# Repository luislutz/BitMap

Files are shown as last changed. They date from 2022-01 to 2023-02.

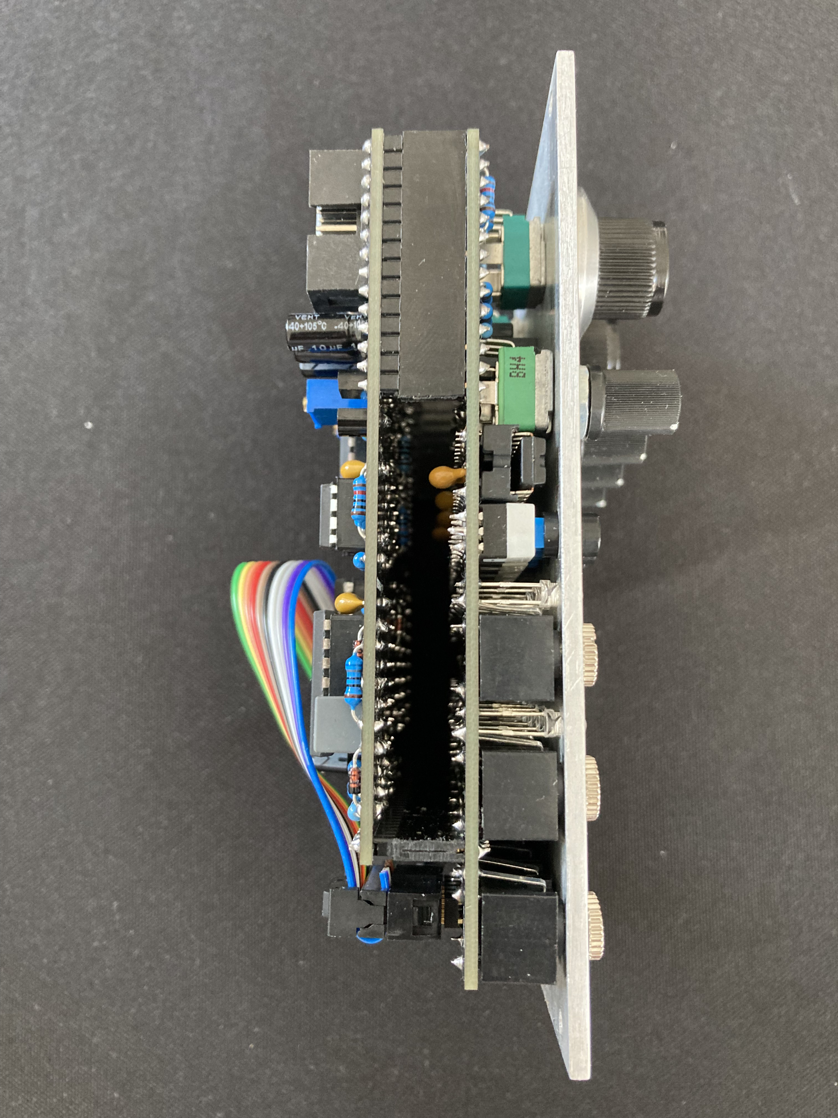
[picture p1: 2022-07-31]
Pictures/Side View.jpeg

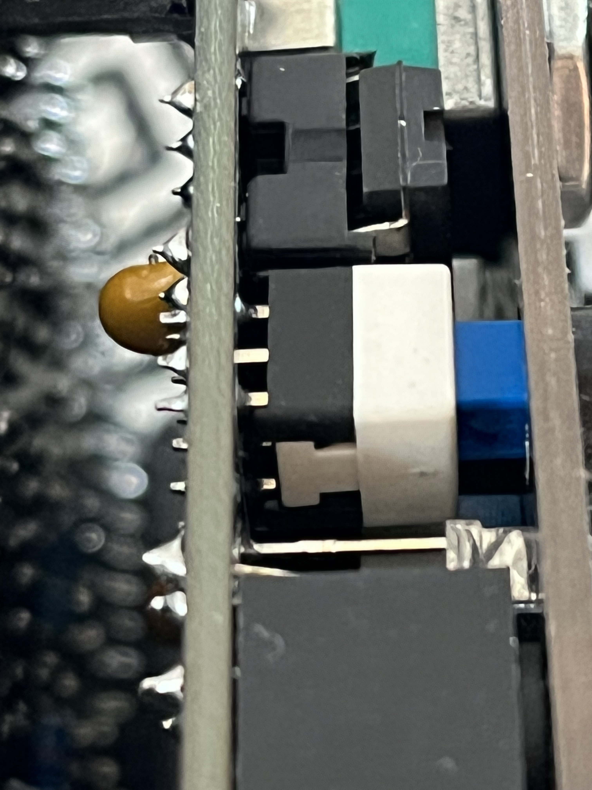
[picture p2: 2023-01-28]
Pictures/963E008B-FA3E-4BF9-BDF7-06B0E4106F40.jpeg

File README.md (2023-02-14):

# BitMap
Multifunction Eurorack Module with 8 Bit parallel ADC and DAC in the Heart. Main selling points:
- most versatile Bitcrusher in Eurorack with passive LPF
- infinite Sample and Hold with slew, works with 1v/oct pitch CV!
- Halftone Chromatic, Chromatic and weird scales Quantizer (every 2nd, 4th, 8th, 16th)
- inspiring Drum/Gate Sequencer with 8 Channels
- VCA and Ringmodulator
- White Noise, 8 types of digital noise and processed White Noise (Bitcrushed, Sample Rate reduced and Filtered to your taste)

## Features and Functions:

Conversion of analog voltage in 8 Bit digital value
Possibility of swapping individual bits and switching them off manually, 
aswell as removing the bits in order via the voltage controlled Bitcrush-Knob
Reconversion of digital 8 Bit value in analog voltage

ADC and DAC can be used as seperate units with the same clock (onboard pulsegenerator or external trigger/gates):

ADC: 1 analog input, 8 digital bit outputs derived from the input voltage (Gates), additional Clip output wich goes high when the input voltage is bigger than the ADC range, this produces hard clipping

DAC: 8 digital inputs (Gates), 1 analog output derived from the digital input values. Possibitlity to set the refence voltage of the DAC externally via an analog gain input, works as a VCA with unipolar Voltage or Ringmodulator with bipolar Voltage

Normalled white noise to the analog input of the ADC aswell as a seperate unprocessed noise output. This gives direct access to 9 flavours of Digital Noise at the ADC Bit outputs and Clip output and a processed white noise at the analog output of the DAC without having to add some other modules or cables. The processed white noise can of course be bitcrushed and samplerate reduced as you wish aswell. Random Voltages in S and Hold style are achievable too with really slow clock rate. With the passive Slew limiter (LPF) at the output the noise can be filtered too and it is possible to slew the Sample and Hold Voltages.

Because the value of the incoming analog voltage is stored in Digital realm. The module does act as a Sample and Hold circuit with infinite holding time and zero voltage drop. Using this module to sample and hold pitch CV is no problem.

The coolest feature by far is the precise mapping of the 256 steps in 8 Bit to the V/Oct scale at the analog input and output. To set the module up for quantizing Pitch CV, just turn the input and output level knobs all the way up. Now a Voltage of 0 (C3) at the input equals a digital word of 10000000, C#3 would be 10000010, D3 = 10000100, D#3 = 10000110 and so on. one Sem,itone equals two steps in the Digital realm. So the minimum voltage value will be -5.33V (00000000, G#-3) and the maximum voltage is 5.25 (11111110, D#8). The Quantizing range is therefor over 10 Octaves of Notes. There are many possibilities for quantizing pitch cv. For Chromatic quantizing, disable the lowest value bit. if you want everey 2nd, 4th, 8th semitone and so on,disable more bits or make any weird combination of bits to make weird scales that are impossible using a normal quantizer. Normal scales like Major Minor or Phrigyian are not so easy to replicate with this module.

## Different Use Cases:

- Voltage controlled Bitreducing of CV and Audio signals
- Voltage controlled Reducing of Sample Rate for CV and Audio Signals (S&H)
- Random Voltage and Gate Source
- Sequencing Drums with mutes (up to 9 channels)
- Quantizing of pitch CV (Chromatic and unusal scales)
- VCA and Ringmodulator (after AD->DA Conversion on the Output)
- Sequencer for pitch CV
- infinite Sample and Hold with external trigger
- Pitch Sequence Transformation to related, but different Sequences
- Slew and Low pass filtering of output with switchable range (passive)
- Strange Wavefolder (swapping or switching individula bits of Audio)
- Distortion (hardclipping at 10vpp)
- Noise source (1 unprocessed Noise white noise outoput, 9 times digital noise with different flavours, and one 8 bit white noise processable with Bitmap as you wish) 
- Compatible with Leibniz system from Xaoc via Leibniz headers on the back of the module!

## Building Instructions:

This is no easy build! Althought it is mostly throughhole, the Module is really packed with Components and ICs.
The hardest part is to solder the 0603 SMD Resistors and keep them unharmed during the rest of the soldering

Start with the 0603 SMD resistors on the backside of the front PCB!

Using Leibniz Subsystem:
There are 9 Jumpers on the front PCB. if you solder these jumpers, the optional connectors for the Leibniz subsystem are bridged and wont be needed anymore. If you want to use the Leibniz subsystem now or in the Future, please make sure you dont solder the jumpers and solder the connectors for the Leibniz subsystem.
Before soldering the Thonkiconn Jacks (3.5mm mono jacks) make sure to solder the Leibniz Headers first. Make sure the pins of the Leibniz connector is flush with the Frontside of the PCB, that way they dont interfere with the 3.5mm Mono Jacks on the oter side of the PCB.

After you have made your decision, start putting everything else in by starting with the most slim parts (Resistors, diodes) and end with the Biggest parts (Elko Caps, trimmers, pin headers)
Solder the panel components with the panel already mounted on them to make sure the parts will align with the holes in the PCB Panel

## Calibraton:

Set Up: 
- SampleRate Knob ~70% to the right
- Bitcrush Knob 100% to the left
- Input Level Knob 100% to the left
- CV Scale Knob 100% to the left
- Slew Pot 100% to the left
- Output Pot 100% to the right
- All individual Bit Buttons are not pressed, e.g. Bits are all active!

there are 6 calibrating trimpotentiometers in total to be adjusted:

1. Input Offset trim RV5 10K:
Turn the Input Level Knob on the Panel completely to the left first. Listen to the Noise Output Jack. Turn the Noise Trim Potentiometer completely down, so that there is absolutely no Nosie left at the Noise Output Jack. This should result in less flickering of the Bit LEDS on the Panel (This is really important). Now youre set for precise calibration. Adjust the Input Offset Trim Potentiometer so that the LEDs light up with this pattern from left to right without flickering: 00000001 (EG Only BIT8 is set active)

2. Input Scale trim RV4 10K:
Take a constant voltage source with exactly 5V (coming from a sequencer or similar) and plug it in the analog voltage input. Turn the Input Level Knob on the Frontpanel completely up (100% to the right). Adjust the Input Scale Trim Potentiometer so that LEDs light up with this pattern from left to right: 00011111    ---> repeat Step 1. and Step 2. until it stays at the correct LED-Pattern with the corresponding input voltage and no jitter.

3. Output Offset trim RV6 2K:
Keep the precise 5V source plugged in. Turn the Input Level Knob on the panel to zero again. Connect the output to a Voltage Meter or to the V/Oct input of an Oscillator that is already well calibrated to 1V/Oct. Make sure you see the Pattern 00000001 on the LEDs. Adjust the Output Offset Trim until the Output Voltage equals excactly 0V or your oscillator doesnt change pitch when unpluuging the cable from the V/Oct input (should be the case for a good calibrated VCO with 0V at the cable)

4. Output Scale trim RV9 2K:
Keep the precise 5V source plugged in. Turn the Input Voltage Knob on the Panel to max (100% to the right). Now the LED-Pattern should be (00011111) again. Leave the Analog Voltage Output connected to the oscillator or the Voltage Meter. Adjust the Output Scale Trim until the output matcehs excactly 5 volts or the Oscillator is playing 5 Octaves above when compared to Step 3.
--> your Input and Output Scales and Offsets are now set correctly to 1V/Oct

5. Max Sample Rate trim RV12 2K:
Feed a Sinewave into the analog input Jack. Listen to the output of the Module. Turn the Sample Rate Knob on the panel to max value (100% to the right). Adjust the Sample Rate Trim to minimal noise on the output (Hint: if the sample rate just exceeds audible range its perfect there). if the Sample Rate trim is set to high. The ADC stalls when turning the SR pot all the way to the Right, you can unstall the ADC by turning it quite down, but its better to set that trimmer in a way that the ADC doest lock at all when the Sample Rate Pot is at its max Setting (100% to the right)

6. Noise Level trim RV3 100K: 
Turn the Input Level Knob again completely to the left. Now turn the Noise trimpot up until there is a slight flickering at the LEDs on the Panel (because the dac is very quickly switching States because of increased signal noise at the input). Turn it slightly back so that the flickering stops. Noise level is now set to Max Level without interference to the input Voltage. Any higher and the Readings of Voltages to the Analog Voltage input get inprecise and noisy. For max precision on Pitch CV you can even turn the noise trim completely down :) if your more after noisy behaviour it doesnt matter that much and you can turn up the noise quite abit :D

if you have any questions regarding the building or calibration Process you can write me an email to luis.lutz95@gmail.com 

Thanks for thaking the challenge to build one of these!!!

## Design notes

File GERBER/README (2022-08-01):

Gerber files for Production of PCB. Noncommercial use only. If your interested in selling these PCBs please contact me beforehand. If you want to build this for yourself, go ahead and have fun!

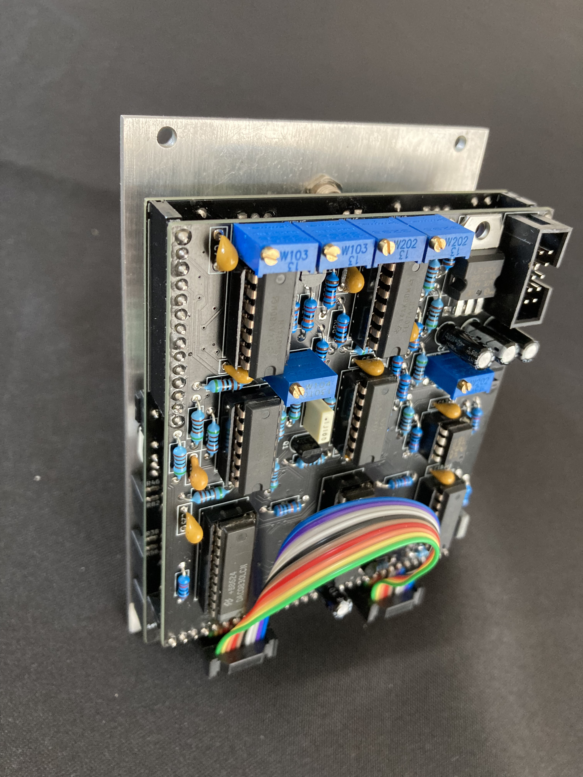
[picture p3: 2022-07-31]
Pictures/Diagonal View.jpeg

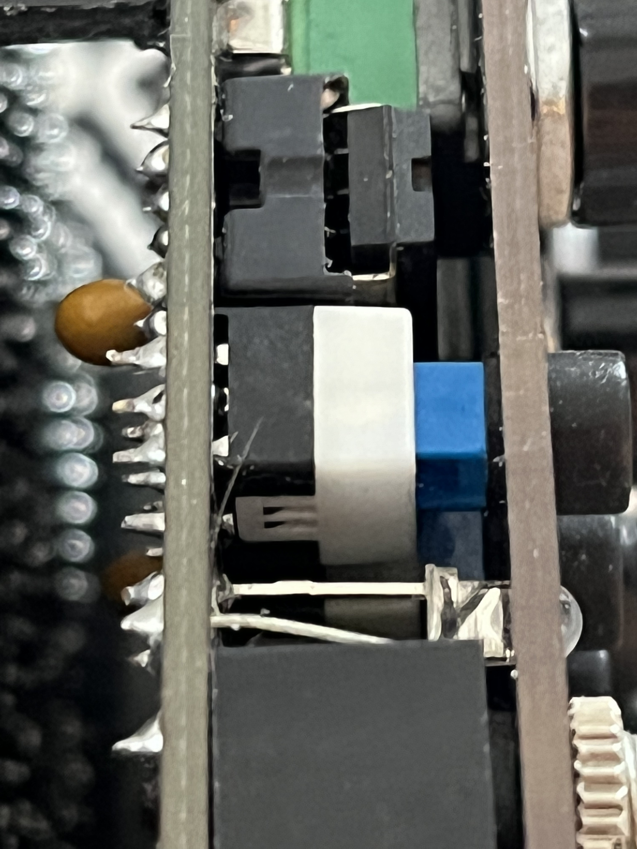
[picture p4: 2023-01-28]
Pictures/B39D2387-7268-4ADA-9052-7F4AAE6AAACA.jpeg

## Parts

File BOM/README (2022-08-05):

This is the Bill of Materials to order every component you need to successfully build a BitMap model after you got you PCBs and Panel ready :)

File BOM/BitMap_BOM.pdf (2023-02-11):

Part number on Schematic | Value | Amount | Package | Link for ordering | Comment
Resistors SMD
R31, R32, R33, R34, R35, R36, R37, R38,
R83, R83, R85, R86, R87, R88, R89, R90
1K | 16 0603 SMD | 1K Ohm 1/10W 1% 0603 SMD Chip Resistors (taydaelectronics.com)
R72, R76, R77, R78, R79, R80, R81, R82 | 10K | 8 0603 SMD | 10K Ohm 1/10W 1% 0603 SMD Chip Resistors (taydaelectronics.com)
R39, R40, R41, R42, R43, R44, R45, R46 | LED resistors ADC ~3.3K | | 8 0603 SMD | 4.7K Ohm 1/10W 1% 0603 SMD Chip Resistors (taydaelectronics.com) | Resitor for setting the brightness on the ADC LEDs Running on 5V. Recommended value for clear yellow LEDs is 3.3K. Best is to test with the LEDs you want to use and test for brightness with some resistor values with 5V before ordering the SMD resistors
R49, R50, R51. R52, R53, R54, R55, R56 | LED resistors DAC ~75K | | 8 0603 SMD | 100K Ohm 1/10W 1% 0603 SMD Chip Resistors (taydaelectronics.com) | Resitor for setting the brightness on the DAC LEDs. Running on 12V. Recommended value for clear green LEDs is 75K. Best is to test with the LEDs you want to use and test for brightness with some different resistor values with 12V before ordering th SMD resistors Resistors THT
R74 | 470R | 1 THT 1/4W | Save time Easy Ordering Page for 1/4W 1% Resistors (taydaelectronics.com)
R68 | 680R | 1 THT 1/4W | Save time Easy Ordering Page for 1/4W 1% Resistors (taydaelectronics.com)
R70, R15, R23, R29, R30, R69, R92, R94 | 1K | 9 THT 1/4W | Save time Easy Ordering Page for 1/4W 1% Resistors (taydaelectronics.com) | R29 is the Resistor which sets the brightness of the Clip LED running on 5V. Recommended value for clear red LED is 1K. Best is to test with the LEDs you want to use and test for brightness with some resistor values with the right supplyvoltage before ordering th SMD resistors
R63 | 1.8K | 1 THT 1/4W | Save time Easy Ordering Page for 1/4W 1% Resistors (taydaelectronics.com)
R5, R6, R7, R8, R9, R10, R11, R12, R16, R17,
R18, R19, R20, R21, R22
5.1K | 15 THT 1/4W | Save time Easy Ordering Page for 1/4W 1% Resistors (taydaelectronics.com)

R24, R26, R25, R27, R28, R47, R48, R57,
R58, R65, R66, R67, R71, R75, R91, R93
10K | 16 THT 1/4W | Save time Easy Ordering Page for 1/4W 1% Resistors (taydaelectronics.com)
R59, R62 | 20K | 2 THT 1/4W | Save time Easy Ordering Page for 1/4W 1% Resistors (taydaelectronics.com)
R73 | 22K | 1 THT 1/4W | Save time Easy Ordering Page for 1/4W 1% Resistors (taydaelectronics.com)
R2, R60, R61 | 47K | 3 THT 1/4W | Save time Easy Ordering Page for 1/4W 1% Resistors (taydaelectronics.com)
R15 | 91K | 1 THT 1/4W | Save time Easy Ordering Page for 1/4W 1% Resistors (taydaelectronics.com)
R1, R3, R95, | 100K | 3 THT 1/4W | Save time Easy Ordering Page for 1/4W 1% Resistors (taydaelectronics.com)
R4, | 200k | 1 THT 1/4W | Save time Easy Ordering Page for 1/4W 1% Resistors (taydaelectronics.com)
R14 | 220K | 1 THT 1/4W | Save time Easy Ordering Page for 1/4W 1% Resistors (taydaelectronics.com)
R64 | 1M | 1 THT 1/4W | Save time Easy Ordering Page for 1/4W 1% Resistors (taydaelectronics.com)
Capacitors
C4, C5, C6, C7, C8, C9, C10, C11, C12, C13,
C14, C15, C16, C17, C18, C25
100n | 16 Ceramic | https://www.taydaelectronics.com/100nf-50v-multilayer-monolithic-ceramic-capacitor-2-54mm-vishay.html
C21 | 22n | 1 Film | 22nF 0.022uF 100V 5% Polyester Film Box Type Capacitor (taydaelectronics.com)
C20 | 68n | 1 Film | 68nF 0.068uF 100V 5% Polyester Film Box Type Capacitor (taydaelectronics.com)
C1 | 100n | 1 Film | 100nF 0.1uF 100V 5% Polyester Film Box Type Capacitor (taydaelectronics.com)
C23 | 680n | 1 Film | 680nF 0.68uF 100V 5% Polyester Film Box Type Capacitor (taydaelectronics.com)
C2, C3, C19, C24 | 10u | 4 Elko | 10uF 50V 105C Radial Electrolytic Capacitor 5x11mm (taydaelectronics.com)
Diodes
D1 | Clip LED | 1 LED 3mm round LED 3mm Red Water Clear Ultra Bright (taydaelectronics.com)
D2, D3, D4, D5, D6, D7, D8, D9 | LEDs ADC | 8 LED 3mm round LED 3mm Orange Water Clear (taydaelectronics.com) | Tayda has no yellow LEDs at the moment….
D10, D11, D12, D13, D14, D15, D16, D17 | LEDs DAC | 8 LED 3mm round LED 3mm Green Water Clear Super Bright (taydaelectronics.com)
D19 | BAT43 | 1
D18, D20 | 1N4148 | 2 | 1N4148 Switching Signal Diode (taydaelectronics.com)
Variable Resistors
RV3 | 100K | 1 Trim | 100K OHM TRIMMER POTENTIOMETER CERMET 25 TURNS 3296W (taydaelectronics.com)
RV6, RV9, RV12 | 2K | 3 Trim | 2K OHM CERMET TRIMMER POTENTIOMETER 25 TURNS 3296W (taydaelectronics.com)
RV4, RV5, RV14 | 10K | 3 Trim | 10K OHM TRIMMER POTENTIOMETER CERMET 25 TURNS 3296W (taydaelectronics.com)
RV10 | 10K Knurled Shaft | 1 Pot | 10K OHM Linear Taper Potentiometer Spline Shaft PCB Mount 9mm (taydaelectronics.com) | linear Taper
RV2, RV11, RV8 | 100K Knurled Shaft | 3 Pot | 100K OHM Linear Taper Potentiometer Spline Shaft PCB Mount 9mm (taydaelectronics.com) | linear Taper
RV1, RV7 | 100K Round Shaft | 2 Pot | 100K OHM Linear Taper Potentiometer Round Shaft PCB 9mm (taydaelectronics.com) | linear Taper
Transistors
Q1, Q3, Q4 | BC547 | 3 TO-92 | BC547 Transistor NPN 45V 0.1A (taydaelectronics.com)
Q2 | BC557 | 1 TO-92 | BC557 Transistor PNP 45V 0.1A TO-92 BC557B-KEC/P (taydaelectronics.com)
Jacks and Connections
J1, J2, J4, J5, J6, J7, J8, J9, J10, J11, J12, J13, J14, J15, J16, J17, J18, J19, J20, J21, J22, J23, J24, J25 | Thonkiconn type Mono Jack | 24 | | PJ-3001F 3.5mm Mono Phone Jack (taydaelectronics.com)
J3 | Pin Header 2x5 Male Boxed | 1 | 10 Pin Box Header Connector 2.54mm (taydaelectronics.com)
J32, J33 | Pin Header 2x5 Male P2.54 | 2
J27, J30 | Pin Header 1x14 Female | 2 | 40 Pin 2.54 mm Single Row Female Pin Header (taydaelectronics.com) | Cut to lenght!
J26, J31 | Pin Header 1x14 Male | 2 | 40 Pin 2.54 mm Single Row Pin Header Strip (taydaelectronics.com) | Cut to lenght!
J28 | Pin Header 1x31 Female | 1 | 40 Pin 2.54 mm Single Row Female Pin Header (taydaelectronics.com) | Cut to lenght!
J29 | Pin Header 1x31 Male | 1 | 40 Pin 2.54 mm Single Row Pin Header Strip (taydaelectronics.com) | Cut to lenght!
Switches
S1, S2, S3, S4, S5, S6, S7, S8, S9 | DPDT latching switch 7x7mm | 9 | PUSH BUTTON SWITCH DC 30V 0.1A DPDT 7x7mm (taydaelectronics.com)
Integrated Circuits
U1 | MCP6002 | 1 DIP-8
U2, U3, U4, U5 | TL074 | 4 DIP-14 | TL074 Quad Operational Amplifier J-FET PDIP-14 TL074CN (taydaelectronics.com)
U8 | CD4069 | 1 DIP-14 | CD4069UBE CD4069 4069 Hex Inverter IC (taydaelectronics.com)
U6, U7 | LM324 | 2 DIP-14 | LM324N LM324 324 Low Power Quad Op-Amp IC (taydaelectronics.com)
U9, U10 | CD4066 | 2 DIP-14 | CD4066 4066 IC CMOS QUAD BILATERAL SWITCH (taydaelectronics.com)
U11 | L7805 | 1 TO-220-3 | LM7805 L7805 7805 Voltage Regulator IC 5V 1.5A (taydaelectronics.com)
U12 | TL431 | 1 TO-92 | TL431ACL TL431 PRECISION SHUNT REGULATOR (taydaelectronics.com)
IC1 | ADC0820CCN | 1 DIP-20
IC2 | DAC0830LJ | 1 DIP-20
IC - Sockets
E1 | IC Socket | 1 DIP-8 | 8 pin DIP IC Socket Adaptor Solder Type (taydaelectronics.com)
E2, E3, E4, E5, E6, E7, E8, E9, E10 | IC Socket | 9 DIP-14 | 14 pin DIP IC Socket Adaptor Solder Type (taydaelectronics.com)
EC1, EC2 | IC Socket | 2 DIP-20 | 20 pin DIP IC Socket Adaptor Solder Type (taydaelectronics.com)
External Parts
K1, K2 | Alu Pot Knobs 22mm | | 2 6.35mm shaft | Aluminum Knob with Delta Mark (taydaelectronics.com)
K1, K2, K3, K4 | Black Pot Knobs slim | | 4 knurled shaft | 10 Pcs Black Plastic Potentiometer Rotary Control Knobs Caps for 6mm Dia Sh'yg | eBay
K5, K6, K7, K8, K9, K10, K11, K12, K13 | Black Switch Caps | 9 | Push Button Switch Caps Black Color 6x5mm (taydaelectronics.com) | other colours than black availiable at Tayda
W1,W2 | IDC Ribboncable 10 Pin | 2 | 10 Conductor AWG 28 Flat Ribbon Cable 1FT (30cm) (taydaelectronics.com)
J34, J35, J36, J37 | IDC Header Female 5x2 Pin | 4 | IDC Socket Connector 2.54mm 2*4 Pin (taydaelectronics.com)

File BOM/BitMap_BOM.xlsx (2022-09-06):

Part number on Schematic | Value | Amount | Package | Link for ordering | Comment
Resistors SMD
R31, R32, R33, R34, R35, R36, R37, R38, R83, R83, R85, R86, R87, R88, R89, R90 | 1K | 16 | 0603 SMD | 1K Ohm 1/10W 1% 0603 SMD Chip Resistors (taydaelectronics.com) (https://www.taydaelectronics.com/50-x-1k-ohm-1-10w-1-0603-smd-chip-resistors.html)
R72, R76, R77, R78, R79, R80, R81, R82 | 10K | 8 | 0603 SMD | 10K Ohm 1/10W 1% 0603 SMD Chip Resistors (taydaelectronics.com) (https://www.taydaelectronics.com/50-x-10k-ohm-1-10w-1-0603-smd-chip-resistors.html)
R39, R40, R41, R42, R43, R44, R45, R46 | LED resistors ADC ~3.3K | 8 | 0603 SMD | 4.7K Ohm 1/10W 1% 0603 SMD Chip Resistors (taydaelectronics.com) (https://www.taydaelectronics.com/resistors/smd-chip-resistors/0603/50-x-4-7k-ohm-1-10w-1-0603-smd-chip-resistors.html) | Resitor for setting the brightness on the ADC LEDs Running on 5V. Recommended value for clear yellow LEDs is 3.3K. Best is to test with the LEDs you want to use and test for brightness with some resistor values with 5V before ordering th SMD resistors
R49, R50, R51. R52, R53, R54, R55, R56 | LED resistors DAC ~75K | 8 | 0603 SMD | 100K Ohm 1/10W 1% 0603 SMD Chip Resistors (taydaelectronics.com) (https://www.taydaelectronics.com/resistors/smd-chip-resistors/0603/50-x-100k-ohm-1-10w-1-0603-smd-chip-resistors.html) | Resitor for setting the brightness on the DAC LEDs. Running on 12V. Recommended value for clear green LEDs is 75K. Best is to test with the LEDs you want to use and test for brightness with some different resistor values with 12V before ordering th SMD resistors
Resistors THT
R74 | 470R | 1 | THT 1/4W | Save time Easy Ordering Page for 1/4W 1% Resistors (taydaelectronics.com) (https://www.taydaelectronics.com/test-group-2-2762.html)
R68 | 680R | 1 | THT 1/4W | Save time Easy Ordering Page for 1/4W 1% Resistors (taydaelectronics.com) (https://www.taydaelectronics.com/test-group-2-2762.html)
R70, R13, R23, R29, R30, R69, R92, R94 | 1K | 8 | THT 1/4W | Save time Easy Ordering Page for 1/4W 1% Resistors (taydaelectronics.com) (https://www.taydaelectronics.com/test-group-2-2762.html) | R29 is the Resistor which sets the brightness of the Clip LED running on 5V. Recommended value for clear red LED is 1K. Best is to test with the LEDs you want to use and test for brightness with some resistor values with the right supplyvoltage before ordering th SMD resistors
R63 | 1.8K | 1 | THT 1/4W | Save time Easy Ordering Page for 1/4W 1% Resistors (taydaelectronics.com) (https://www.taydaelectronics.com/test-group-2-2762.html)
R5, R6, R7, R8, R9, R10, R11, R12, R16, R17, R18, R19, R20, R21, R22 | 5.1K | 15 | THT 1/4W | Save time Easy Ordering Page for 1/4W 1% Resistors (taydaelectronics.com) (https://www.taydaelectronics.com/test-group-2-2762.html)
R24, R26, R25, R27, R28, R47, R48, R57, R58, R65, R66, R67, R71, R75, R91, R93 | 10K | 16 | THT 1/4W | Save time Easy Ordering Page for 1/4W 1% Resistors (taydaelectronics.com) (https://www.taydaelectronics.com/test-group-2-2762.html)
R59, R62 | 20K | 2 | THT 1/4W | Save time Easy Ordering Page for 1/4W 1% Resistors (taydaelectronics.com) (https://www.taydaelectronics.com/test-group-2-2762.html)
R73 | 22K | 1 | THT 1/4W | Save time Easy Ordering Page for 1/4W 1% Resistors (taydaelectronics.com) (https://www.taydaelectronics.com/test-group-2-2762.html)
R2, R60, R61 | 47K | 3 | THT 1/4W | Save time Easy Ordering Page for 1/4W 1% Resistors (taydaelectronics.com) (https://www.taydaelectronics.com/test-group-2-2762.html)
R15 | 91K | 1 | THT 1/4W | Save time Easy Ordering Page for 1/4W 1% Resistors (taydaelectronics.com) (https://www.taydaelectronics.com/test-group-2-2762.html)
R1, R3, R95, | 100K | 3 | THT 1/4W | Save time Easy Ordering Page for 1/4W 1% Resistors (taydaelectronics.com) (https://www.taydaelectronics.com/test-group-2-2762.html)
R4, | 200k | 1 | THT 1/4W | Save time Easy Ordering Page for 1/4W 1% Resistors (taydaelectronics.com) (https://www.taydaelectronics.com/test-group-2-2762.html)
R14 | 220K | 1 | THT 1/4W | Save time Easy Ordering Page for 1/4W 1% Resistors (taydaelectronics.com) (https://www.taydaelectronics.com/test-group-2-2762.html)
R64 | 1M | 1 | THT 1/4W | Save time Easy Ordering Page for 1/4W 1% Resistors (taydaelectronics.com) (https://www.taydaelectronics.com/test-group-2-2762.html)
Capacitors
C4, C5, C6, C7, C8, C9, C10, C11, C12, C13, C14, C15, C16, C17, C18, C25 | 100n | 16 | Ceramic | https://www.taydaelectronics.com/100nf-50v-multilayer-monolithic-ceramic-capacitor-2-54mm-vishay.html
C21 | 22n | 1 | Film | 22nF 0.022uF 100V 5% Polyester Film Box Type Capacitor (taydaelectronics.com) (https://www.taydaelectronics.com/22nf-0-022uf-63v-5-polyester-film-box-type-capacitor.html)
C20 | 68n | 1 | Film | 68nF 0.068uF 100V 5% Polyester Film Box Type Capacitor (taydaelectronics.com) (https://www.taydaelectronics.com/68nf-0-068uf-100v-5-polyester-film-box-type-capacitor.html)
C1 | 100n | 1 | Film | 100nF 0.1uF 100V 5% Polyester Film Box Type Capacitor (taydaelectronics.com) (https://www.taydaelectronics.com/0-1uf-100v-5-polyester-film-box-type-capacitor.html)
C23 | 680n | 1 | Film | 680nF 0.68uF 100V 5% Polyester Film Box Type Capacitor (taydaelectronics.com) (https://www.taydaelectronics.com/0-68uf-100v-5-polyester-film-box-type-capacitor-size-small.html)
C2, C3, C19, C24 | 10u | 4 | Elko | 10uF 50V 105C Radial Electrolytic Capacitor 5x11mm (taydaelectronics.com) (https://www.taydaelectronics.com/10uf-50v-105c-radial-electrolytic-capacitor-5x11mm.html)
Diodes
D1 | Clip LED | 1 | LED 3mm round | LED 3mm Red Water Clear Ultra Bright (taydaelectronics.com) (https://www.taydaelectronics.com/led-3mm-red-water-clear-ultra-bright.html)
D2, D3, D4, D5, D6, D7, D8, D9 | LEDs ADC | 8 | LED 3mm round | LED 3mm Orange Water Clear (taydaelectronics.com) (https://www.taydaelectronics.com/led-3mm-orange-water-clear.html) | Tayda has no yellow LEDs at the moment….
D10, D11, D12, D13, D14, D15, D16, D17 | LEDs DAC | 8 | LED 3mm round | LED 3mm Green Water Clear Super Bright (taydaelectronics.com) (https://www.taydaelectronics.com/led-3mm-green-water-clear-super-bright.html)
D19 | BAT43 | 1
D18, D20 | 1N4148 | 2 |  | 1N4148 Switching Signal Diode (taydaelectronics.com) (https://www.taydaelectronics.com/1n4148-switching-signal-diode.html)
Variable Resistors
RV3 | 100K | 1 | Trim | 100K OHM TRIMMER POTENTIOMETER CERMET 25 TURNS 3296W (taydaelectronics.com) (https://www.taydaelectronics.com/100k-ohm-trimmer-potentiometer-cermet-25-turns-3296w.html)
RV6, RV9, RV12 | 2K | 3 | Trim | 2K OHM CERMET TRIMMER POTENTIOMETER 25 TURNS 3296W (taydaelectronics.com) (https://www.taydaelectronics.com/2k-ohm-cermet-trimmer-potentiometer-25-turns-3296w.html)
RV4, RV5, RV14 | 10K | 3 | Trim | 10K OHM TRIMMER POTENTIOMETER CERMET 25 TURNS 3296W (taydaelectronics.com) (https://www.taydaelectronics.com/10k-ohm-trimmer-potentiometer-cermet-25-turns-3296w.html)
RV10 | 10K Knurled Shaft | 1 | Pot | 10K OHM Linear Taper Potentiometer Spline Shaft PCB Mount 9mm (taydaelectronics.com) (https://www.taydaelectronics.com/10k-ohm-linear-taper-potentiometer-knurled-plastic-round-shaft-pcb-9mm.html) | linear Taper
RV2, RV11, RV8 | 100K Knurled Shaft | 3 | Pot | 100K OHM Linear Taper Potentiometer Spline Shaft PCB Mount 9mm (taydaelectronics.com) (https://www.taydaelectronics.com/100k-ohm-linear-taper-potentiometer-knurled-plastic-spline-shaft-pcb-9mm.html) | linear Taper
RV1, RV7 | 100K Round Shaft | 2 | Pot | 100K OHM Linear Taper Potentiometer Round Shaft PCB 9mm (taydaelectronics.com) (https://www.taydaelectronics.com/100k-ohm-linear-taper-potentiometer-round-shaft-pcb-9mm.html) | linear Taper
Transistors
Q1, Q3, Q4 | BC547 | 3 | TO-92 | BC547 Transistor NPN 45V 0.1A (taydaelectronics.com) (https://www.taydaelectronics.com/bc547-transistor-npn-45v-0-1a.html)
Q2 | BC557 | 1 | TO-92 | BC557 Transistor PNP 45V 0.1A TO-92 BC557B-KEC/P (taydaelectronics.com) (https://www.taydaelectronics.com/bc557-transistor-pnp-45v-0-1a-to-92-bc557b-kec-p.html)
Jacks and Connections
J1, J2, J4, J5, J6, J7, J8, J9, J10, J11, J12, J13, J14, J15, J16, J17, J18, J19, J20, J21, J22, J23, J24, J25 | Thonkiconn type Mono Jack | 24 |  | PJ-3001F 3.5mm Mono Phone Jack (taydaelectronics.com) (https://www.taydaelectronics.com/pj-3001f-3-5-mm-mono-phone-jack.html)
J3 | Pin Header 2x5 Male Boxed | 1 |  | 10 Pin Box Header Connector 2.54mm (taydaelectronics.com) (https://www.taydaelectronics.com/10-pin-box-header-connector-2-54mm.html)
J32, J33 | Pin Header 2x5 Male P2.54 | 2
J27, J30 | Pin Header 1x14 Female | 2 |  | 40 Pin 2.54 mm Single Row Female Pin Header (taydaelectronics.com) (https://www.taydaelectronics.com/40-pin-2-54-mm-single-row-female-pin-header.html) | Cut to lenght!
J26, J31 | Pin Header 1x14 Male | 2 |  | 40 Pin 2.54 mm Single Row Pin Header Strip (taydaelectronics.com) (https://www.taydaelectronics.com/40-pin-2-54-mm-single-row-pin-header-strip.html) | Cut to lenght!
J28 | Pin Header 1x31 Female | 1 |  | 40 Pin 2.54 mm Single Row Female Pin Header (taydaelectronics.com) (https://www.taydaelectronics.com/40-pin-2-54-mm-single-row-female-pin-header.html) | Cut to lenght!
J29 | Pin Header 1x31 Male | 1 |  | 40 Pin 2.54 mm Single Row Pin Header Strip (taydaelectronics.com) (https://www.taydaelectronics.com/40-pin-2-54-mm-single-row-pin-header-strip.html) | Cut to lenght!
Switches
S1, S2, S3, S4, S5, S6, S7, S8, S9 | DPDT latching switch 7x7mm | 9 |  | PUSH BUTTON SWITCH DC 30V 0.1A DPDT 7x7mm (taydaelectronics.com) (https://www.taydaelectronics.com/push-button-switch-dc-30v-0-1a-dpdt-7x7mm.html)
Integrated Circuits
U1 | MCP6002 | 1 | DIP-8
U2, U3, U4, U5 | TL074 | 4 | DIP-14 | TL074 Quad Operational Amplifier J-FET PDIP-14 TL074CN (taydaelectronics.com) (https://www.taydaelectronics.com/tl074-quad-operational-amplifier-j-fet-pdip-14-tl074cn.html)
U8 | CD4069 | 1 | DIP-14 | CD4069UBE CD4069 4069 Hex Inverter IC (taydaelectronics.com) (https://www.taydaelectronics.com/cd4069ube-cd4069-4069-hex-inverter-ic.html)
U6, U7 | LM324 | 2 | DIP-14 | LM324N LM324 324 Low Power Quad Op-Amp IC (taydaelectronics.com) (https://www.taydaelectronics.com/lm324n-lm324-324-low-power-quad-op-amp-ic.html)
U9, U10 | CD4066 | 2 | DIP-14 | CD4066 4066 IC CMOS QUAD BILATERAL SWITCH (taydaelectronics.com) (https://www.taydaelectronics.com/cd4066-4066-ic-cmos-quad-bilateral-switch.html)
U11 | L7805 | 1 | TO-220-3 | LM7805 L7805 7805 Voltage Regulator IC 5V 1.5A (taydaelectronics.com) (https://www.taydaelectronics.com/lm7805-l7805-7805-voltage-regulator-ic-5v-1-5a.html)
U12 | TL431 | 1 | TO-92 | TL431ACL TL431 PRECISION SHUNT REGULATOR (taydaelectronics.com) (https://www.taydaelectronics.com/tl431acl-tl431-precision-shunt-regulator.html)
IC1 | ADC0820CCN | 1 | DIP-20
IC2 | DAC0830LJ | 1 | DIP-20
IC - Sockets
E1 | IC Socket | 1 | DIP-8 | 8 pin DIP IC Socket Adaptor Solder Type (taydaelectronics.com) (https://www.taydaelectronics.com/8-pin-dip-ic-socket-adaptor-solder-type.html)
E2, E3, E4, E5, E6, E7, E8, E9, E10 | IC Socket | 9 | DIP-14 | 14 pin DIP IC Socket Adaptor Solder Type (taydaelectronics.com) (https://www.taydaelectronics.com/14-pin-dip-ic-socket-adaptor-solder-type.html)
EC1, EC2 | IC Socket | 2 | DIP-20 | 20 pin DIP IC Socket Adaptor Solder Type (taydaelectronics.com) (https://www.taydaelectronics.com/20-pin-dip-ic-socket-adaptor-solder-type.html)
External Parts
K1, K2 | Alu Pot Knobs 22mm | 2 | 6.35mm shaft | Aluminum Knob with Delta Mark (taydaelectronics.com) (https://www.taydaelectronics.com/aluminum-knob.html)
K1, K2, K3, K4 | Black Pot Knobs slim | 4 | knurled shaft | 10 Pcs Black Plastic Potentiometer Rotary Control Knobs Caps for 6mm Dia Sh'yg | eBay (https://www.ebay.de/itm/354203495558?hash=item52782c6c86:g:D3gAAOSw6GJaKRqu)
K5, K6, K7, K8, K9, K10, K11, K12, K13 | Black Switch Caps | 9 |  | Push Button Switch Caps Black Color 6x5mm (taydaelectronics.com) (https://www.taydaelectronics.com/push-button-switch-caps-black-color-6-x-5-mm.html) | other colours than black availiable at Tayda
W1,W2 | IDC Ribboncable 10 Pin | 2 |  | 10 Conductor AWG 28 Flat Ribbon Cable 1FT (30cm) (taydaelectronics.com) (https://www.taydaelectronics.com/awg-28-10-conductor-flat-ribbon-cable-1ft-30cm.html)
J34, J35, J36, J37 | IDC Header Female 5x2 Pin | 4 |  | IDC Socket Connector 2.54mm 2*4 Pin (taydaelectronics.com) (https://www.taydaelectronics.com/idc-socket-connector-2-54mm-2-5-pin.html)

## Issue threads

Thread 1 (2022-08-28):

BOM correction

Ghouly, 2022-08-28:
You currently have R15 listed twice in the BOM. I believe the R15 listed as 1K THT Resistor, should actually be R13 as that one appears to be absent.

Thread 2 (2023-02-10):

Missing SMD Resistors in BOM

TimoJohannes, 2023-02-10:
Hi!
Just got a set of PCBs/Panel of this, and I wanted to start the build. I then noticed that the SMD Resistors on the Control board are missing from the BOM.
Looks like a super fun module, it would be great to add them back to the BOM for an easier build :)

Cheers!

luislutz, 2023-02-11:
Hey,

Thanks for the hint! Youre right, on the pdf version there was the smd resistor tab closed, but the Resistors were in the excel file already :) i have updated the pdf BOM to also have the SMD resistors shown. Have fun building and when you have problems getting your module to work or calibrated please come back at me!

Best regards Luis

Von meinem iPhone gesendet

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

TimoJohannes, 2023-02-28:
Totally forgot to answer here, I was a tad blind, not noticing the closed tab, lol.
Thanks for the update, I have everything built now, so I can start testing. Crossing my fingers here for no magic smoke. If I stumble onto some problem, I will definitly get back to you :)

Closed 2023-02-28.

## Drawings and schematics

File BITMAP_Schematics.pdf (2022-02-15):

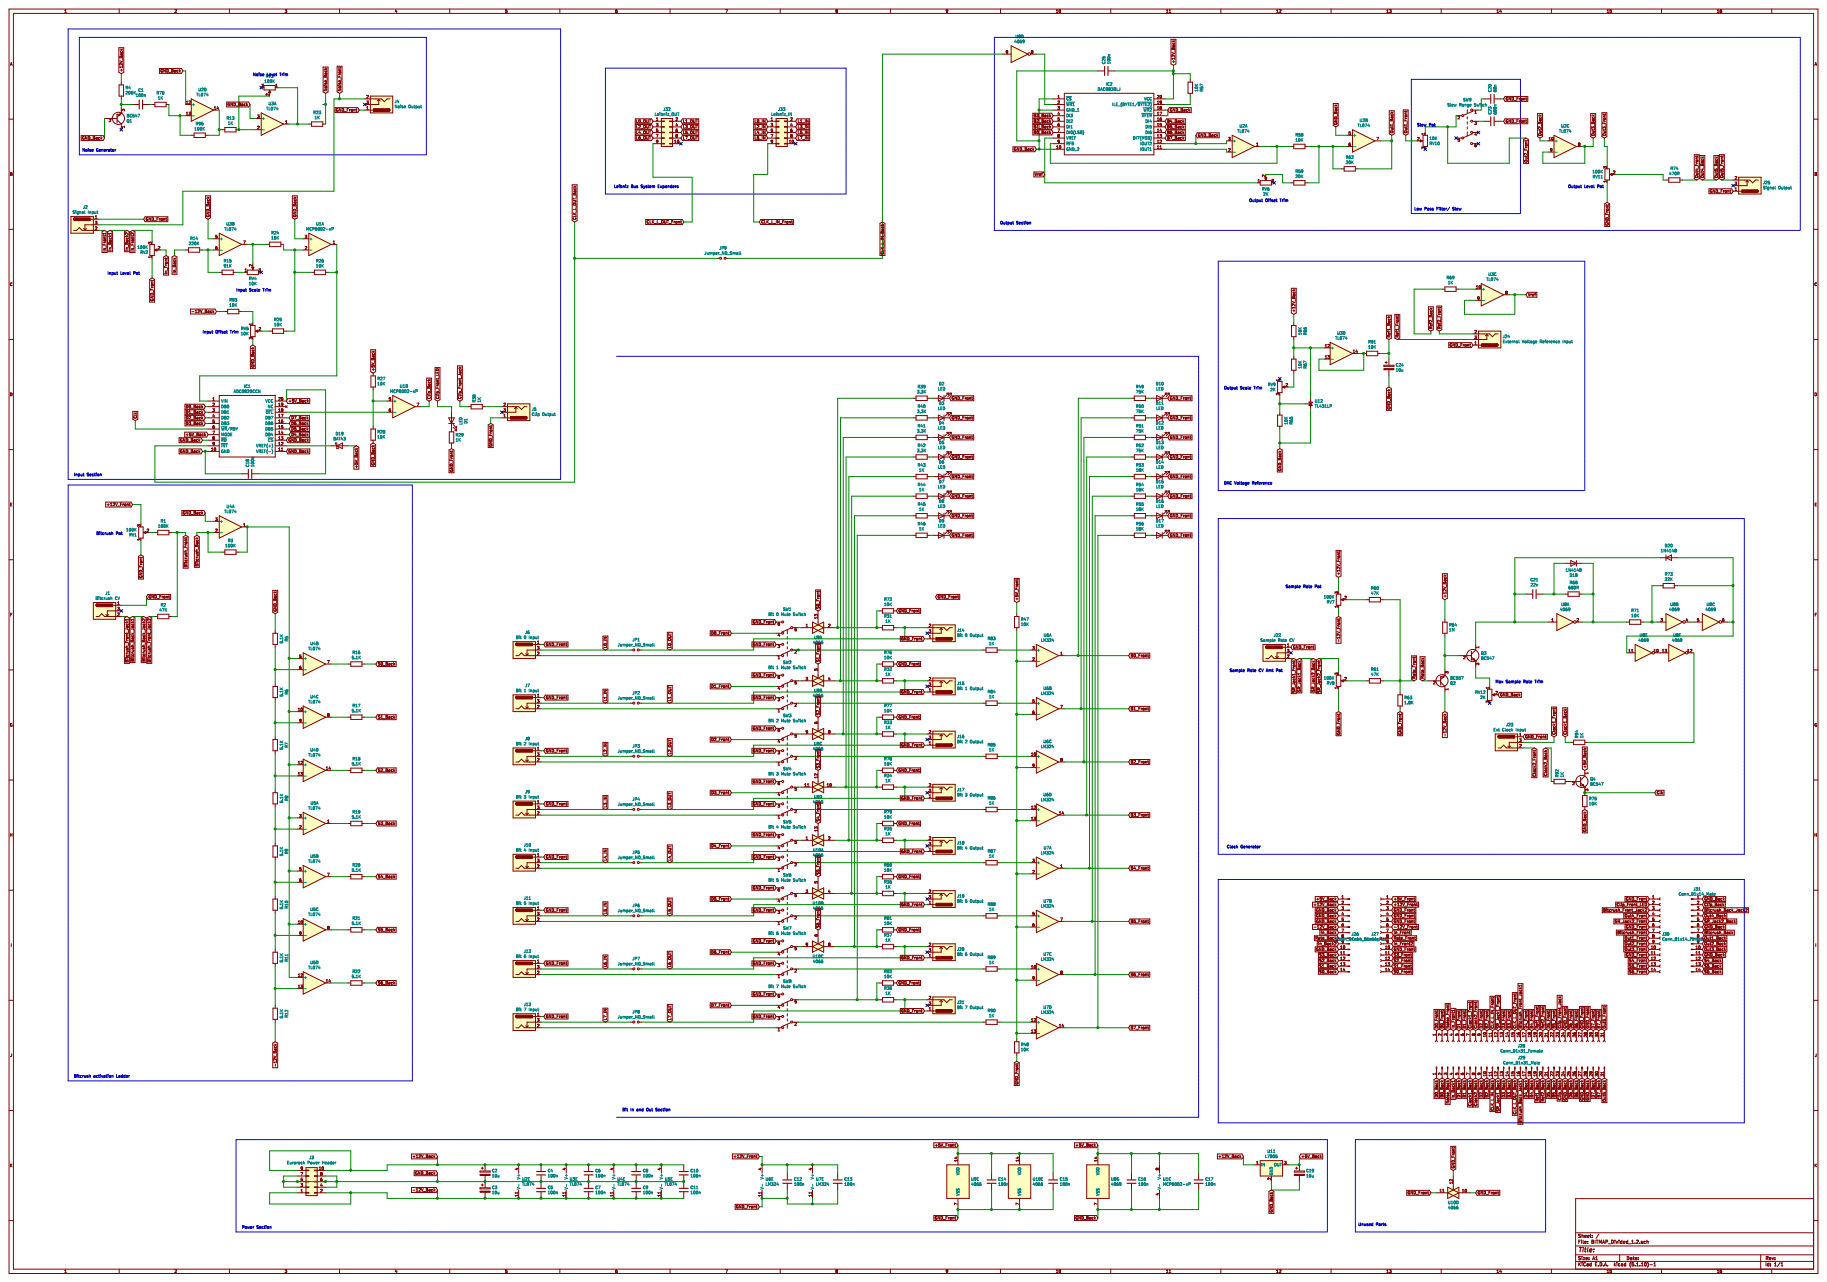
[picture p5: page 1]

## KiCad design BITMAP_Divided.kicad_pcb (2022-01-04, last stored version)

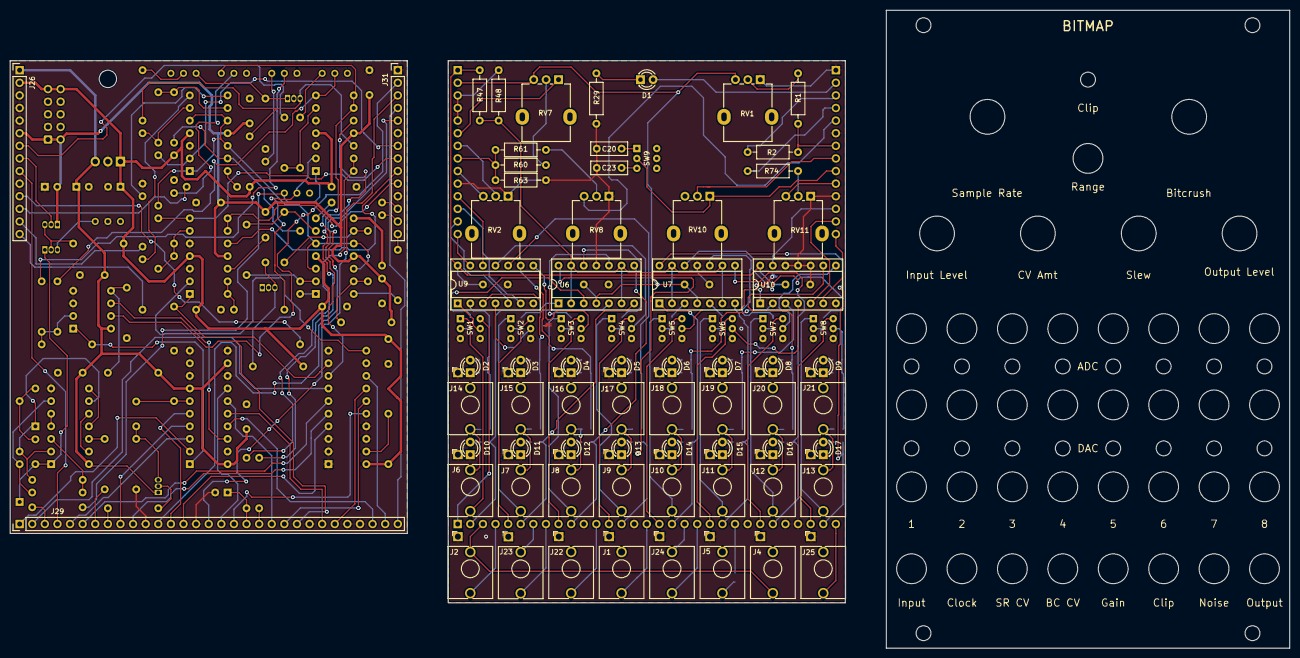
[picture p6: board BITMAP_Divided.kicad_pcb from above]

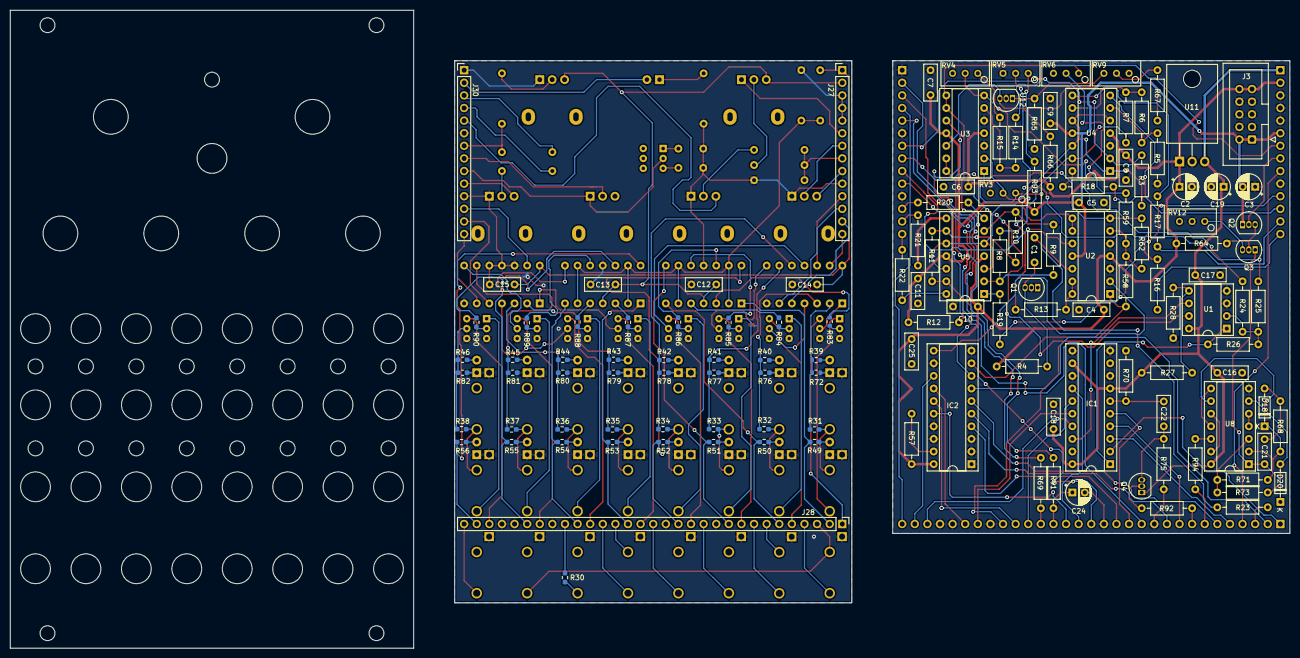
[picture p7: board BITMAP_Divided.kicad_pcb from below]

Board: 2 copper layers, 257.8 x 128.5 mm, 208 parts (134 on the bottom side), 217 nets.

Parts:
C1, C4, C5, C6, C7, C8, C9, C10, C11, C12, C13, C14, C15, C16, C17, C18, C25: 100n; C_Rect_L7.2mm_W2.5mm_P5.00mm_FKS2_FKP2_MKS2_MKP2
C2, C3, C19, C24: 10u; CP_Radial_D5.0mm_P2.50mm
C20: 68n; C_Rect_L7.2mm_W2.5mm_P5.00mm_FKS2_FKP2_MKS2_MKP2
C21: 2.2n; C_Rect_L7.2mm_W2.5mm_P5.00mm_FKS2_FKP2_MKS2_MKP2
C22: 1n; C_Rect_L7.2mm_W2.5mm_P5.00mm_FKS2_FKP2_MKS2_MKP2
C23: 680n; C_Rect_L7.2mm_W2.5mm_P5.00mm_FKS2_FKP2_MKS2_MKP2
D1, D2, D3, D4, D5, D6, D7, D8, D9, D10, D11, D12, D13, D14, D15, D16, D17: LED; LED_D3.0mm
D18, D20: 1N4148; D_DO-35_SOD27_P7.62mm_Horizontal
IC1: ADC0820CCN; DIP-20_W7.62mm_Socket
IC2: DAC0830LJ; DIP-20_W7.62mm_Socket
J1: Bitcrush CV; Jack_3.5mm_QingPu_WQP-PJ398SM_Vertical_CircularHoles
J2: Signal Input; Jack_3.5mm_QingPu_WQP-PJ398SM_Vertical_CircularHoles
J3: Eurorack Power Header; IDC-Header_2x05_P2.54mm_Vertical
J4: Noise Output; Jack_3.5mm_QingPu_WQP-PJ398SM_Vertical_CircularHoles
J5: Clip Output; Jack_3.5mm_QingPu_WQP-PJ398SM_Vertical_CircularHoles
J6: Bit 0 Input; Jack_3.5mm_QingPu_WQP-PJ398SM_Vertical_CircularHoles
J7: Bit 1 Input; Jack_3.5mm_QingPu_WQP-PJ398SM_Vertical_CircularHoles
J8: Bit 2 Input; Jack_3.5mm_QingPu_WQP-PJ398SM_Vertical_CircularHoles
J9: Bit 3 Input; Jack_3.5mm_QingPu_WQP-PJ398SM_Vertical_CircularHoles
J10: Bit 4 Input; Jack_3.5mm_QingPu_WQP-PJ398SM_Vertical_CircularHoles
J11: Bit 5 Input; Jack_3.5mm_QingPu_WQP-PJ398SM_Vertical_CircularHoles
J12: Bit 6 Input; Jack_3.5mm_QingPu_WQP-PJ398SM_Vertical_CircularHoles
J13: Bit 7 Input; Jack_3.5mm_QingPu_WQP-PJ398SM_Vertical_CircularHoles
J14: Bit 0 Output; Jack_3.5mm_QingPu_WQP-PJ398SM_Vertical_CircularHoles
J15: Bit 1 Output; Jack_3.5mm_QingPu_WQP-PJ398SM_Vertical_CircularHoles
J16: Bit 2 Output; Jack_3.5mm_QingPu_WQP-PJ398SM_Vertical_CircularHoles
J17: Bit 3 Output; Jack_3.5mm_QingPu_WQP-PJ398SM_Vertical_CircularHoles
J18: Bit 4 Output; Jack_3.5mm_QingPu_WQP-PJ398SM_Vertical_CircularHoles
J19: Bit 5 Output; Jack_3.5mm_QingPu_WQP-PJ398SM_Vertical_CircularHoles
J20: Bit 6 Output; Jack_3.5mm_QingPu_WQP-PJ398SM_Vertical_CircularHoles
J21: Bit 7 Output; Jack_3.5mm_QingPu_WQP-PJ398SM_Vertical_CircularHoles
J22: Sample Rate CV; Jack_3.5mm_QingPu_WQP-PJ398SM_Vertical_CircularHoles
J23: Ext Clock Input; Jack_3.5mm_QingPu_WQP-PJ398SM_Vertical_CircularHoles
J24: External Voltage Reference Input; Jack_3.5mm_QingPu_WQP-PJ398SM_Vertical_CircularHoles
J25: Signal Output; Jack_3.5mm_QingPu_WQP-PJ398SM_Vertical_CircularHoles
J26, J31: Conn_01x14_Male; PinHeader_1x14_P2.54mm_Vertical
J27, J30: Conn_01x14_Female; PinHeader_1x14_P2.54mm_Vertical
J28: Conn_01x31_Female; PinHeader_1x31_P2.54mm_Vertical
J29: Conn_01x31_Male; PinHeader_1x31_P2.54mm_Vertical
Q1, Q3, Q4: BC547; TO-92_Inline
Q2: BC557; TO-92_Inline
R1, R3, R15: 100K; R_Axial_DIN0207_L6.3mm_D2.5mm_P10.16mm_Horizontal
R2, R60, R61: 47K; R_Axial_DIN0207_L6.3mm_D2.5mm_P10.16mm_Horizontal
R4: 200K; R_Axial_DIN0207_L6.3mm_D2.5mm_P10.16mm_Horizontal
R5, R6, R7, R8, R9, R10, R11, R12, R16, R17, R18, R19, R20, R21, R22: 5.1K; R_Axial_DIN0207_L6.3mm_D2.5mm_P10.16mm_Horizontal
R13, R23, R29, R69, R75, R92, R94: 1K; R_Axial_DIN0207_L6.3mm_D2.5mm_P10.16mm_Horizontal
R14: 220K; R_Axial_DIN0207_L6.3mm_D2.5mm_P10.16mm_Horizontal
R24, R25, R26, R27, R28, R47, R48, R57, R58, R65, R66, R67, R70, R71, R91: 10K; R_Axial_DIN0207_L6.3mm_D2.5mm_P10.16mm_Horizontal
R30, R31, R32, R33, R34, R35, R36, R37, R38, R40, R41, R42, R43, R44, R45, R46, R49, R50, R51, R52, R53, R54, R55, R56, R84, R85, R86, R87, R88, R89, R90: 1K; R_0603_1608Metric_Pad0.98x0.95mm_HandSolder
R39, R83: 1K; R_0603_1608Metric
R59, R62: 20K; R_Axial_DIN0207_L6.3mm_D2.5mm_P10.16mm_Horizontal
R63: 1.8K; R_Axial_DIN0207_L6.3mm_D2.5mm_P10.16mm_Horizontal
R64: 1M; R_Axial_DIN0207_L6.3mm_D2.5mm_P10.16mm_Horizontal
R68: 680R; R_Axial_DIN0207_L6.3mm_D2.5mm_P10.16mm_Horizontal
R72: 10K; R_0603_1608Metric
R73: 22K; R_Axial_DIN0207_L6.3mm_D2.5mm_P10.16mm_Horizontal
R74: 470R; R_Axial_DIN0207_L6.3mm_D2.5mm_P10.16mm_Horizontal
R76, R77, R78, R79, R80, R81, R82: 10K; R_0603_1608Metric_Pad0.98x0.95mm_HandSolder
R93: 33K; R_Axial_DIN0207_L6.3mm_D2.5mm_P10.16mm_Horizontal
RV1, RV2, RV7, RV8, RV11: 100K; Potentiometer_Alpha_RD901F-40-00D_Single_Vertical
RV3: 100K; Potentiometer_Bourns_3296W_Vertical
RV4, RV5: 10K; Potentiometer_Bourns_3296W_Vertical
RV6, RV9, RV12: 2K; Potentiometer_Bourns_3296W_Vertical
RV10: 10K; Potentiometer_Alpha_RD901F-40-00D_Single_Vertical
SW1: Bit 0 Mute Switch; 7x7Switch
SW2: Bit 1 Mute Switch; 7x7Switch
SW3: Bit 2 Mute Switch; 7x7Switch
SW4: Bit 3 Mute Switch; 7x7Switch
SW5: Bit 4 Mute Switch; 7x7Switch
SW6: Bit 5 Mute Switch; 7x7Switch
SW7: Bit 6 Mute Switch; 7x7Switch
SW8: Bit 7 Mute Switch; 7x7Switch
SW9: Slew Range Switch; 7x7Switch
U1: MCP6002-xP; DIP-8_W7.62mm_Socket
U2, U3, U4, U5: TL074; DIP-14_W7.62mm_Socket
U6, U7: LM324; DIP-14_W7.62mm_Socket
U8: 4069; DIP-14_W7.62mm_Socket
U9, U10: 4066; DIP-14_W7.62mm_Socket
U11: L7805; TO-220-3_Horizontal_TabDown
U12: TL431LP; TO-92_Inline

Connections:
+5V_Back: C16.1, C17.1, C18.2, C19.1, IC1.7, IC1.12, IC1.20, J26.1, Q4.1, R27.2, U1.8, U8.14, U11.3
+5V_Front: C14.1, C15.1, J27.1, R47.2, U9.14, U10.14
+12V_Back: C2.1, C4.1, C6.1, C8.1, C10.1, C25.2, IC2.20, J3.9, J3.10, J26.2, R4.2, R57.2, R64.2, R66.2, U2.4, U3.4, U4.4, U5.4, U11.1
+12V_Front: C12.1, C13.1, J27.2, RV1.3, RV7.3, U6.4, U7.4
-12V_Back: C3.2, C5.2, C7.2, C9.2, C11.2, J3.1, J3.2, J26.6, Q2.1, R12.1, R93.2, U2.11, U3.11, U4.11, U5.11
-12V_Front: J27.6, RV7.1
B0_Back: IC2.7, J29.2
B0_Front: J28.2, R49.2, U6.1
B1_Back: IC2.6, J29.6
B1_Front: J28.6, R50.2, U6.7
B2_Back: IC2.5, J29.10
B2_Front: J28.10, R51.2, U6.8
B3_Back: IC2.4, J29.14
B3_Front: J28.14, R52.2, U6.14
B4_Back: IC2.16, J29.18
B4_Front: J28.18, R53.2, U7.1
B5_Back: IC2.15, J29.22
B5_Front: J28.22, R54.2, U7.7
B6_Back: IC2.14, J29.26
B6_Front: J28.26, R55.2, U7.8
B7_Back: IC2.13, J29.30
B7_Front: J28.30, R56.2, U7.14
Bitcrush_Back: J31.7, R3.2, U4.2
Bitcrush_Back_Jack1: J29.16, J31.3
Bitcrush_Front: J30.7, R1.1, R2.1
Bitcrush_Front_Jack1: J1.2, J28.16
Bitcrush_Front_Jack2: J30.3, R2.2
Clip_Back: J29.23, J31.2, U1.7
Clip_Front_Jack: J28.23, R30.1
Clip_Front_LED: D1.2, J30.2
Clk: C22.2, IC1.6, R70.2
Clock1_Back: J29.7, R94.1
Clock1_Front: J23.3, J28.7
Clock2_Back: J29.8, R92.1
Clock2_Front: J23.2, J28.8
D0_Back: IC1.2, J29.1
D0_Front: J28.1, SW1.4
D1_Back: IC1.3, J29.5
D1_Front: J28.5, SW2.4
D2_Back: IC1.4, J29.9
D2_Front: J28.9, SW3.4
D3_Back: IC1.5, J29.13
D3_Front: J28.13, SW4.4
D4_Back: IC1.14, J29.17
D4_Front: J28.17, SW5.4
D5_Back: IC1.15, J29.21
D5_Front: J28.21, SW6.4
D6_Back: IC1.16, J29.25
D6_Front: J28.25, SW7.4
D7_Back: IC1.17, J29.29
D7_Front: J28.29, SW8.4
GND_Back: C2.2, C3.1, C4.2, C5.1, C6.2, C7.1, C8.2, C9.1, C10.2, C11.1, C16.2, C17.2, C18.1, C19.2, C24.2, C25.1, IC1.8, IC1.10, IC1.11, IC1.13, IC2.1, IC2.2, IC2.3, IC2.10, IC2.12, IC2.17, IC2.18, J3.3, J3.4, J3.5, J3.6, J3.7, J3.8, J26.3, J26.4, J26.5, J26.10, J29.11, J29.15, J29.24, J29.27, J29.28, J31.1, J31.6, J31.11, Q1.2, R5.2, R28.1, R65.1, R70.1, R75.2, RV5.3, RV12.2, U1.3, U1.4, U2.3, U2.5, U3.3, U3.5, U4.3, U8.7, U11.2, U12.2
GND_Front: C12.2, C13.2, C14.2, C15.2, C20.2, C23.2, D2.1, D3.1, D4.1, D5.1, D6.1, D7.1, D8.1, D9.1, D10.1, D11.1, D12.1, D13.1, D14.1, D15.1, D16.1, D17.1, J1.1, J2.1, J4.1, J5.1, J6.1, J7.1, J8.1, J9.1, J10.1, J11.1, J12.1, J13.1, J14.1, J15.1, J16.1, J17.1, J18.1, J19.1, J20.1, J21.1, J22.1, J23.1, J24.1, J25.1, J27.3, J27.4, J27.5, J27.10, J28.11, J28.15, J28.24, J28.27, J28.28, J30.1, J30.6, J30.11, R29.2, R48.1, R63.1, R72.1, R76.1, R77.1, R78.1, R79.1, R80.1, R81.1, R82.1, RV1.1, RV2.1, RV8.1, RV11.1, SW1.3, SW1.6, SW2.3, SW2.6, SW3.3, SW3.6, SW4.3, SW4.6, SW5.3, SW5.6, SW6.3, SW6.6, SW7.3, SW7.6, SW8.3, SW8.6, U6.11, U7.11, U9.7, U10.7, U10.10, U10.11, U10.12
In_Back: J26.7, R14.2
In_Back1: J26.9, J29.4
In_Front: J27.7, RV2.2
In_Front1: J2.2, J28.4
In_Front2: J27.9, RV2.3
unnamed: C1.1, Q1.3, R4.1
unnamed: C1.2, U2.12
unnamed: C20.1, SW9.1
unnamed: C21.1, D20.1, Q3.1, U8.1
unnamed: C21.2, D18.2, R68.2
unnamed: C22.1, Q4.3, R75.1
unnamed: C23.1, SW9.3
unnamed: D1.1, R29.1
unnamed: D2.2, R39.1
unnamed: D3.2, R40.1
unnamed: D4.2, R41.1
unnamed: D5.2, R42.1
unnamed: D6.2, R43.1
unnamed: D7.2, R44.1
unnamed: D8.2, R45.1
unnamed: D9.2, R46.1
unnamed: D10.2, R49.1
unnamed: D11.2, R50.1
unnamed: D12.2, R51.1
unnamed: D13.2, R52.1
unnamed: D14.2, R53.1
unnamed: D15.2, R54.1
unnamed: D16.2, R55.1
unnamed: D17.2, R56.1
unnamed: D18.1, R68.1, R71.2, U8.2, U8.9
unnamed: D20.2, R73.1, U8.6
unnamed: IC1.1, R26.1, U1.1
unnamed: IC1.18, U1.6
unnamed: IC2.9, R58.2, U2.1
unnamed: IC2.11, U2.2
unnamed: IC2.19, R57.1
unnamed: J5.2, R30.2
unnamed: J6.2, SW1.1
unnamed: J7.2, SW2.1
unnamed: J8.2, SW3.1
unnamed: J9.2, SW4.1
unnamed: J10.2, SW5.1
unnamed: J10.3, J18.2, R35.1
unnamed: J11.2, SW6.1
unnamed: J11.3, J19.2, R36.1
unnamed: J12.2, SW7.1
unnamed: J12.3, J20.2, R37.1
unnamed: J13.2, SW8.1
unnamed: J13.3, J21.2, R38.1
unnamed: J6.3, J14.2, R31.1
unnamed: J7.3, J15.2, R32.1
unnamed: J8.3, J16.2, R33.1
unnamed: J9.3, J17.2, R34.1
unnamed: Q2.3, Q3.2, R64.1
unnamed: Q3.3, RV12.1
unnamed: Q4.2, R92.2
unnamed: R1.2, RV1.2
unnamed: R3.1, U4.1, U4.5, U4.10, U4.12, U5.3, U5.5, U5.10, U5.12
unnamed: R5.1, R6.2, U4.6
unnamed: R6.1, R7.2, U4.9
unnamed: R7.1, R8.2, U4.13
unnamed: R8.1, R9.2, U5.2
unnamed: R10.1, R11.2, U5.9
unnamed: R9.1, R10.2, U5.6
unnamed: R11.1, R12.2, U5.13
unnamed: R13.1, RV3.2, U3.2
unnamed: R13.2, U2.13, U2.14
unnamed: R14.1, R15.2, U3.6
unnamed: R15.1, RV4.1
unnamed: R16.2, U4.7
unnamed: R17.2, U4.8
unnamed: R18.2, U4.14
unnamed: R19.2, U5.1
unnamed: R20.2, U5.7
unnamed: R21.2, U5.8
unnamed: R22.2, U5.14
unnamed: R23.2, RV3.1, U3.1
unnamed: R24.1, R25.1, R26.2, U1.2
unnamed: R24.2, RV4.2, U3.7
unnamed: R25.2, RV5.2
unnamed: R27.1, R28.2, U1.5
unnamed: R31.2, R39.2, R72.2, U9.2
unnamed: R32.2, R40.2, R76.2, U9.3
unnamed: R33.2, R41.2, R77.2, U9.9
unnamed: R34.2, R42.2, R78.2, U9.10
unnamed: R35.2, R43.2, R79.2, U10.2
unnamed: R36.2, R44.2, R80.2, U10.3
unnamed: R37.2, R45.2, R81.2, U10.9
unnamed: R38.2, R46.2, R82.2, SW8.5
unnamed: R47.1, R48.2, U6.2, U6.6, U6.9, U6.13, U7.2, U7.6, U7.9, U7.13
unnamed: R58.1, R59.1, R62.2, U2.6
unnamed: R59.2, RV6.2
unnamed: R60.2, RV7.2
unnamed: R61.2, RV8.2
unnamed: R65.2, RV9.3, U12.1
unnamed: R66.1, R67.2, U3.12, U12.3
unnamed: R67.1, RV9.2
unnamed: R69.1, U3.10
unnamed: R71.1, R73.2, U8.3
unnamed: R74.2, RV11.2
unnamed: R83.1, U6.3
unnamed: R83.2, SW1.2
unnamed: R84.1, U6.5
unnamed: R84.2, SW2.2
unnamed: R85.1, U6.10
unnamed: R85.2, SW3.2
unnamed: R86.1, U6.12
unnamed: R86.2, SW4.2
unnamed: R87.1, U7.3
unnamed: R87.2, SW5.2
unnamed: R88.1, U7.5
unnamed: R88.2, SW6.2
unnamed: R89.1, U7.10
unnamed: R89.2, SW7.2
unnamed: R90.1, U7.12
unnamed: R90.2, SW8.2
unnamed: R91.2, U3.13, U3.14
unnamed: R93.1, RV5.1
unnamed: R94.2, U8.12
unnamed: SW1.5, U9.1
unnamed: SW2.5, U9.4
unnamed: SW3.5, U9.8
unnamed: SW4.5, U9.11
unnamed: SW5.5, U10.1
unnamed: SW6.5, U10.4
unnamed: SW7.5, U10.8
unnamed: U8.4, U8.5
unnamed: U8.10, U8.13
unnamed: U8.8, U8.11
Noise_Back: J29.3, R23.1
Noise_Front: J2.3, J4.2, J28.3
Out1_Back: J31.8, R62.1, U2.7
Out1_Front: J30.8, RV10.2
Out2_Back: J31.9, U2.10
Out2_Front: J30.9, RV10.1, SW9.2
Out3_Back: J31.10, U2.8, U2.9
Out3_Front: J30.10, RV11.3
Out4_Back: J29.31, J31.4
Out4_Front: J30.4, R74.1
Out5_Front: J25.2, J28.31
Rate_Back: J26.8, Q2.2
Rate_Front: J27.8, R60.1, R61.1, R63.2
Ref1_Back: C24.1, J29.19, R91.1
Ref1_Front: J24.3, J28.19
Ref2_Back: J29.20, R69.2
Ref2_Front: J24.2, J28.20
S0_Back: J26.14, R16.1
S0_Front: J27.14, U9.13
S1_Back: J26.13, R17.1
S1_Front: J27.13, U9.5
S2_Back: J26.12, R18.1
S2_Front: J27.12, U9.6
S3_Back: J26.11, R19.1
S3_Front: J27.11, U9.12
S4_Back: J31.12, R20.1
S4_Front: J30.12, U10.13
S5_Back: J31.13, R21.1
S5_Front: J30.13, U10.5
S6_Back: J31.14, R22.1
S6_Front: J30.14, U10.6
SR_Jack1_Back: J29.12, J31.5
SR_Jack1_Front: J22.2, J28.12
SR_Jack2_Front: J30.5, RV8.3
Vref: IC2.8, RV6.1, U3.8, U3.9
